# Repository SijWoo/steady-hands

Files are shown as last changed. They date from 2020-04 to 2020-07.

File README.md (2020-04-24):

# Introduction
This repo contains the src files and hardware for a wearable wrist band that treats chronic shaky hands.

## Background
Tremors make your hands or other parts of your body involuntarily move and shake. Severe cases can even make everday tasks difficult. This device is to let people from mild to severe cases regain control through the use of vibration feedback.

## How it works
Overloading the sensory nerves can surpress the involuntary movement. Vibration motors are implemented inside the wearable to constantly stimulate the nerves.

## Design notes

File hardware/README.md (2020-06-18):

# Hardware
Descriptions and explanations

## Components
| Description | P/N |
| --- | --- |
| Microcontroller | STM32F411CE |
| Vibrating Motors | |
| IMU | BNO055 |

## Microcontroller
The STM32f411CE controls the vibration motors.

## Vibrating Motors
Small motors for phones are repurposed for this project. A transistor interface is needed to drive the required current.

## IMU
The BNO055 uses the I2C interface.

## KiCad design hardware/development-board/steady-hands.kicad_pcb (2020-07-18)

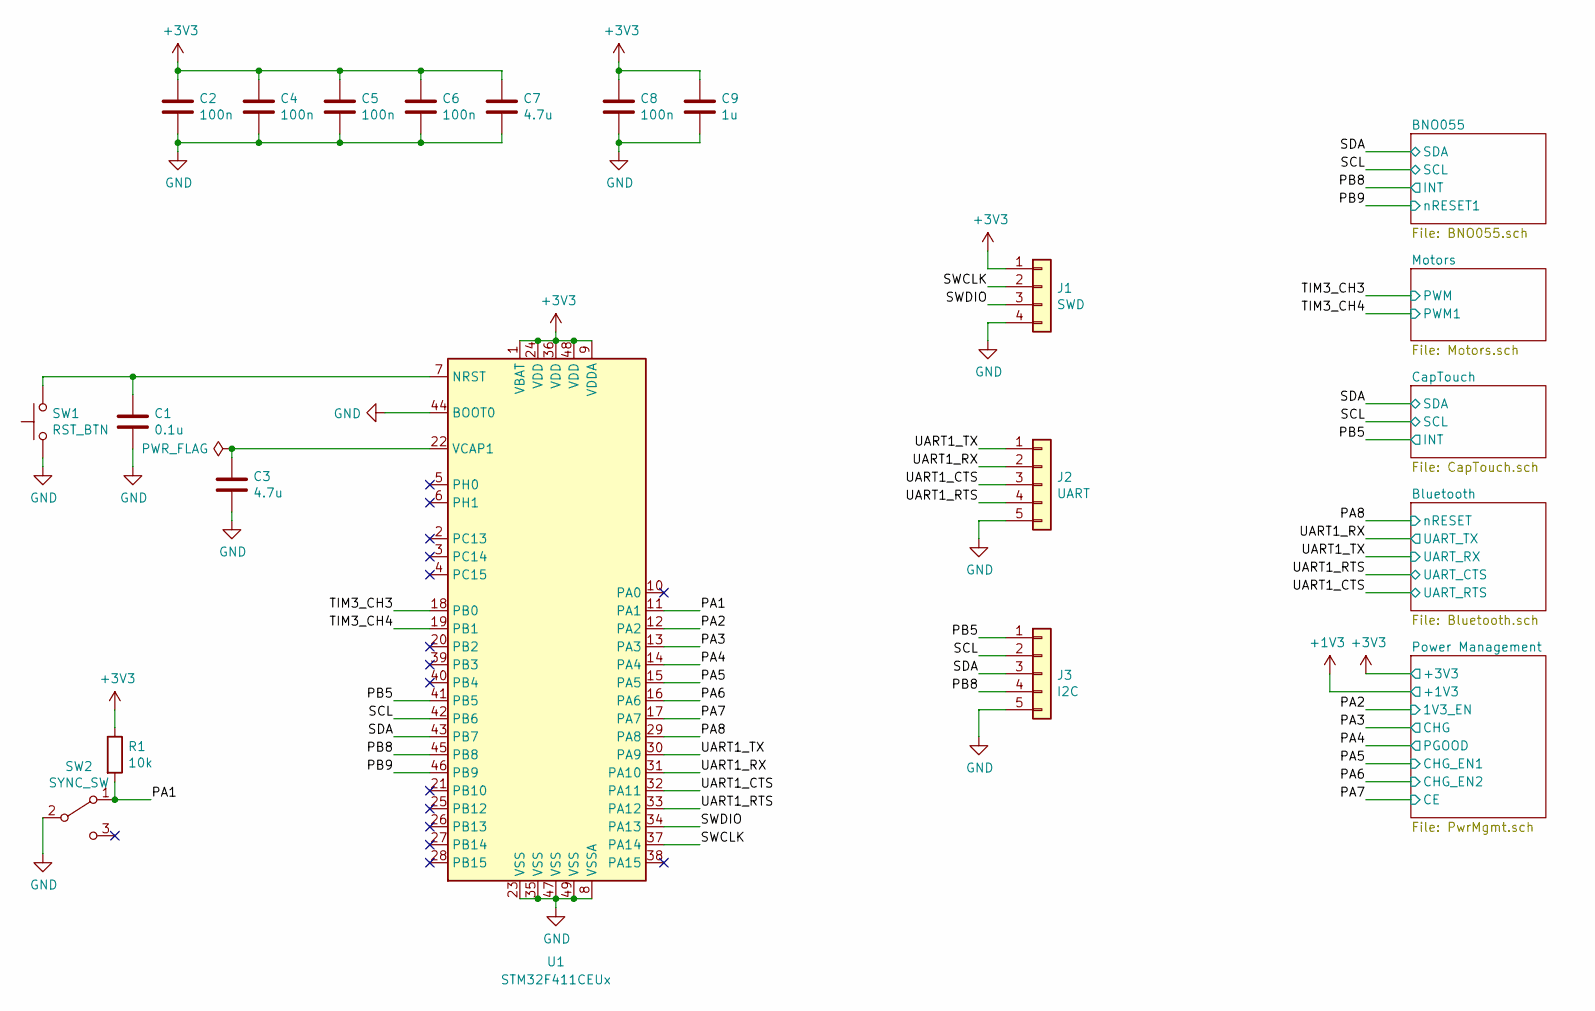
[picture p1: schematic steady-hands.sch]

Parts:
C1: 0.1u; C_0402_1005Metric
C2, C4, C5, C6, C8: 100n; C_0402_1005Metric
C3, C7: 4.7u; C_0402_1005Metric
C9: 1u; C_0402_1005Metric
J1: SWD; PinHeader_1x04_P1.27mm_Vertical
J2: UART; PinHeader_1x05_P1.27mm_Vertical
J3: I2C; PinHeader_1x05_P1.27mm_Vertical
R1: 10k; R_0402_1005Metric
SW1: RST_BTN; SW_SPST_B3U-1000P
SW2: SYNC_SW; EG1224
U1: STM32F411CEUx; QFN-48-1EP_7x7mm_P0.5mm_EP5.6x5.6mm

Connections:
+3V3: C2.1, C4.1, C5.1, C6.1, C7.1, C8.1, C9.1, J1.1, R1.1, U1.1 (VBAT), U1.9 (VDDA), U1.24 (VDD), U1.36 (VDD), U1.48 (VDD); also elsewhere on the board
/PA1: R1.2, SW2.1 (A), U1.11 (PA1)
/PA2: U1.12 (PA2); also elsewhere on the board
/PA3: U1.13 (PA3); also elsewhere on the board
/PA4: U1.14 (PA4); also elsewhere on the board
/PA5: U1.15 (PA5); also elsewhere on the board
/PA6: U1.16 (PA6); also elsewhere on the board
/PA7: U1.17 (PA7); also elsewhere on the board
/PA8: U1.29 (PA8); also elsewhere on the board
/PB5: J3.1, U1.41 (PB5); also elsewhere on the board
/PB8: J3.4, U1.45 (PB8); also elsewhere on the board
/PB9: U1.46 (PB9); also elsewhere on the board
/SCL: J3.2, U1.42 (PB6); also elsewhere on the board
/SDA: J3.3, U1.43 (PB7); also elsewhere on the board
/SWCLK: J1.2, U1.37 (PA14)
/SWDIO: J1.3, U1.34 (PA13)
/TIM3_CH3: U1.18 (PB0); also elsewhere on the board
/TIM3_CH4: U1.19 (PB1); also elsewhere on the board
/UART1_CTS: J2.3, U1.32 (PA11); also elsewhere on the board
/UART1_RTS: J2.4, U1.33 (PA12); also elsewhere on the board
/UART1_RX: J2.2, U1.31 (PA10); also elsewhere on the board
/UART1_TX: J2.1, U1.30 (PA9); also elsewhere on the board
GND: C1.2, C2.2, C3.2, C4.2, C5.2, C6.2, C7.2, C8.2, C9.2, J1.4, J2.5, J3.5, SW1.1, SW2.2 (B), U1.8 (VSSA), U1.23 (VSS), U1.35 (VSS), U1.44 (BOOT0), U1.47 (VSS), U1.49 (VSS); also elsewhere on the board
unnamed: C1.1, SW1.2, U1.7 (NRST)
unnamed: C3.1, U1.22 (VCAP1)

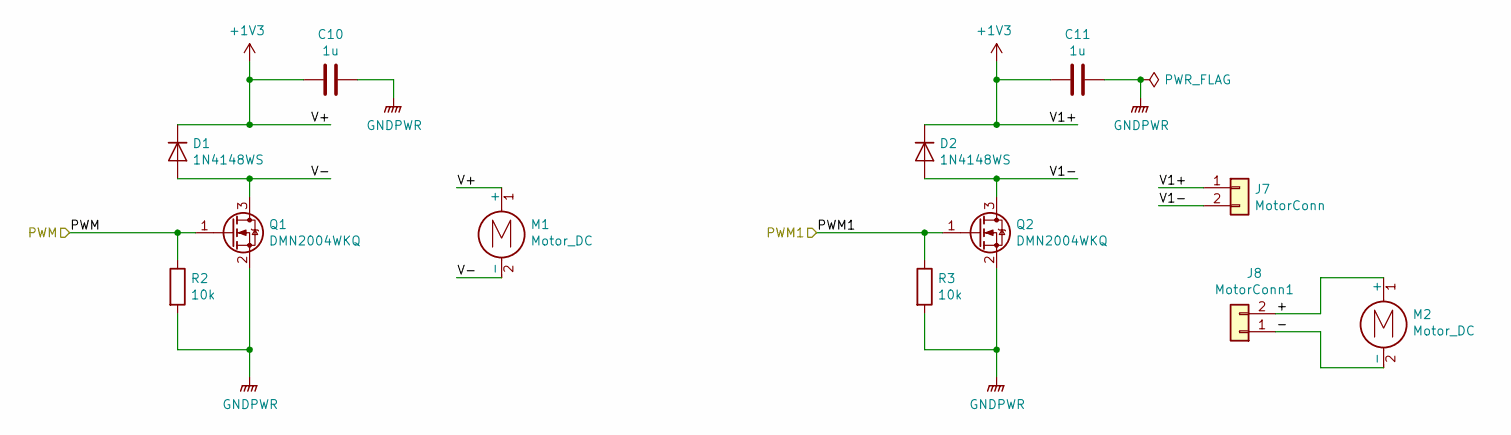
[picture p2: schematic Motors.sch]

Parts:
C10, C11: 1u; C_0402_1005Metric
D1, D2: 1N4148WS; D_SOD-323
J7: MotorConn; PinHeader_1x02_P1.27mm_Vertical
J8: MotorConn1; PinHeader_1x02_P1.27mm_Vertical
M1, M2: Motor_DC; 316040005
Q1, Q2: DMN2004WKQ; SOT-323_SC-70
R2, R3: 10k; R_0402_1005Metric

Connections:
+1V3: C10.2, C11.2, D1.1 (K), D2.1 (K), J7.1, M1.1 (+); also elsewhere on the board
/Motors/V1-: D2.2 (A), J7.2, Q2.3 (D)
/Motors/V-: D1.2 (A), M1.2 (-), Q1.3 (D)
/TIM3_CH3: Q1.1 (G), R2.1; also elsewhere on the board
/TIM3_CH4: Q2.1 (G), R3.1; also elsewhere on the board
GNDPWR: C10.1, C11.1, Q1.2 (S), Q2.2 (S), R2.2, R3.2
unnamed: J8.1, M2.2 (-)
unnamed: J8.2, M2.1 (+)

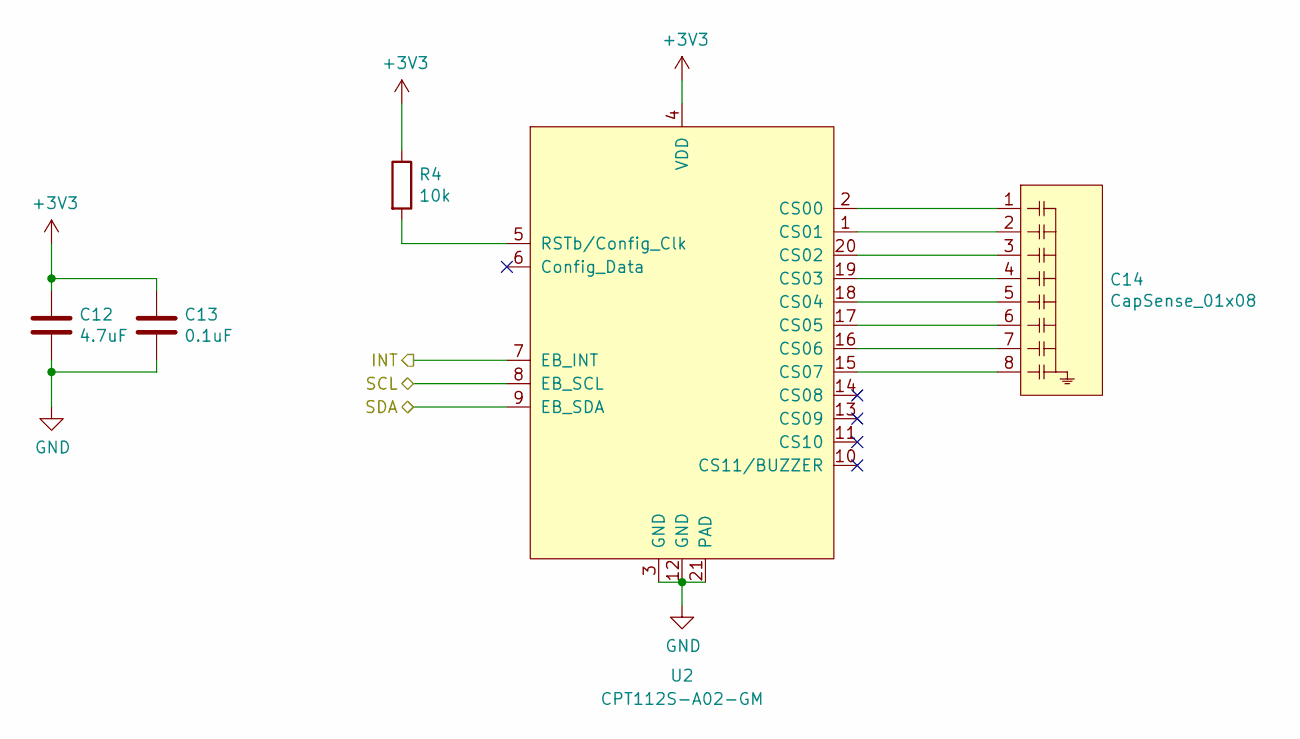
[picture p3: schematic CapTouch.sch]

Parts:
C12: 4.7uF; C_0402_1005Metric
C13: 0.1uF; C_0402_1005Metric
C14: CapSense_01x08; TouchSlider-8_35x10mm
R4: 10k; R_0402_1005Metric
U2: CPT112S-A02-GM

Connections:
+3V3: C12.1, C13.1, R4.1, U2.4 (VDD); also elsewhere on the board
/PB5: U2.7 (EB_INT); also elsewhere on the board
/SCL: U2.8 (EB_SCL); also elsewhere on the board
/SDA: U2.9 (EB_SDA); also elsewhere on the board
GND: C12.2, C13.2, U2.3 (GND), U2.12 (GND), U2.21 (PAD); also elsewhere on the board
unnamed: C14.1, U2.2 (CS00)
unnamed: C14.2, U2.1 (CS01)
unnamed: C14.3, U2.20 (CS02)
unnamed: C14.4, U2.19 (CS03)
unnamed: C14.5, U2.18 (CS04)
unnamed: C14.6, U2.17 (CS05)
unnamed: C14.7, U2.16 (CS06)
unnamed: C14.8, U2.15 (CS07)
unnamed 60: R4.2, U2.5 (RSTb/Config_Clk); also elsewhere on the board

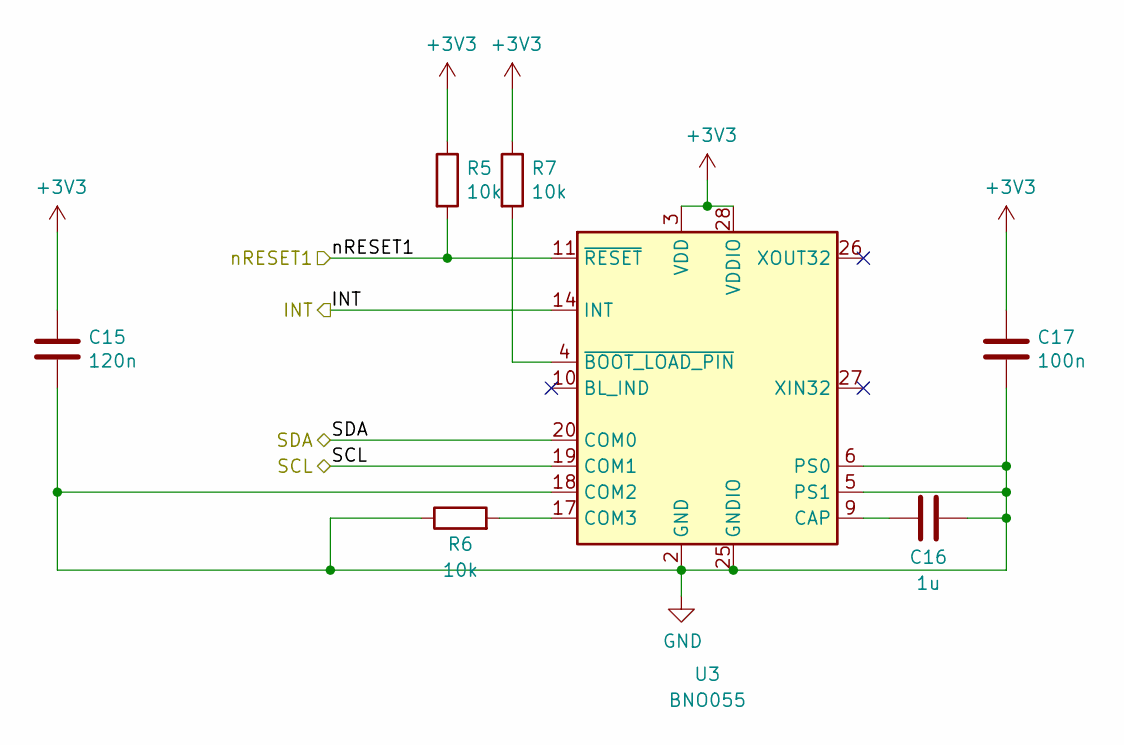
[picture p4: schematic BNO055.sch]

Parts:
C15: 120n; C_0402_1005Metric
C16: 1u; C_0402_1005Metric
C17: 100n; C_0402_1005Metric
R5, R6, R7: 10k; R_0402_1005Metric
U3: BNO055; LGA-28_5.2x3.8mm_P0.5mm

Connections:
+3V3: C15.1, C17.1, R5.1, R7.1, U3.3 (VDD), U3.28 (VDDIO); also elsewhere on the board
/PB8: U3.14 (INT); also elsewhere on the board
/PB9: R5.2, U3.11 (~RESET); also elsewhere on the board
/SCL: U3.19 (COM1); also elsewhere on the board
/SDA: U3.20 (COM0); also elsewhere on the board
GND: C15.2, C16.1, C17.2, R6.1, U3.2 (GND), U3.5 (PS1), U3.6 (PS0), U3.15 (GNDIO), U3.16 (GNDIO), U3.18 (COM2), U3.25 (GNDIO); also elsewhere on the board
unnamed: C16.2, U3.9 (CAP)
unnamed: R6.2, U3.17 (COM3)
unnamed: R7.2, U3.4 (~BOOT_LOAD_PIN)

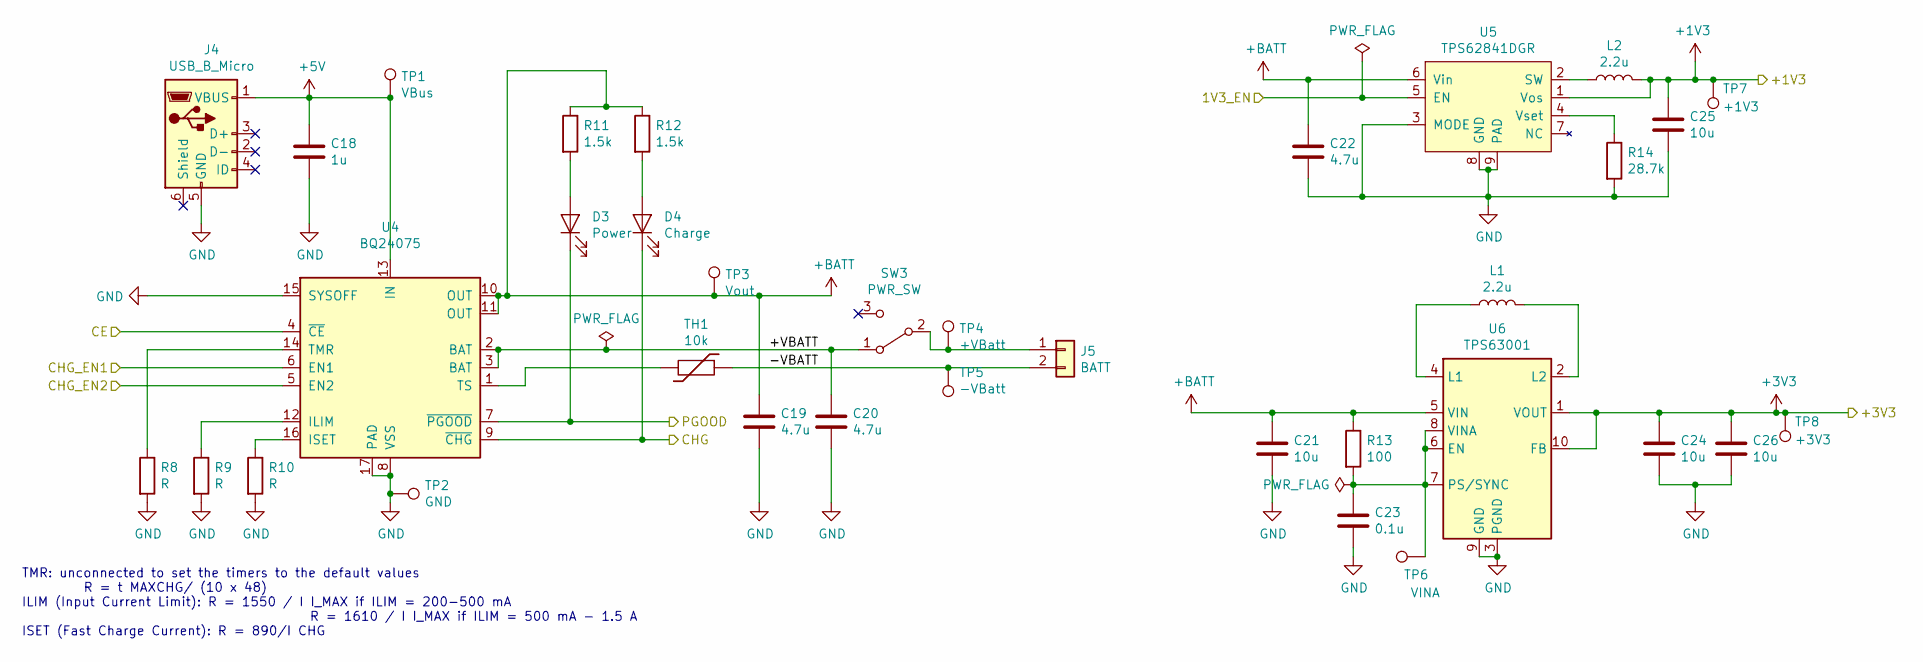
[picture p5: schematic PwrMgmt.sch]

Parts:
C18: 1u; C_0402_1005Metric
C19, C20, C22: 4.7u; C_0402_1005Metric
C21, C24, C25, C26: 10u; C_0402_1005Metric
C23: 0.1u; C_0402_1005Metric
D3: Power; LED_0402_1005Metric
D4: Charge; LED_0402_1005Metric
J4: USB_B_Micro; USB_Micro-B_Molex-105017-0001
J5: BATT; JST_PH_B2B-PH-SM4-TB_1x02-1MP_P2.00mm_Vertical
L1, L2: 2.2u; L_0402_1005Metric
R8, R9, R10: R; R_0402_1005Metric
R11, R12: 1.5k; R_0402_1005Metric
R13: 100; R_0402_1005Metric
R14: 28.7k; R_0402_1005Metric
SW3: PWR_SW; EG1224
TH1: 10k; R_0402_1005Metric
TP1: VBus; TestPoint_Pad_D1.0mm
TP2: GND; TestPoint_Pad_1.0x1.0mm
TP3: Vout; TestPoint_Pad_D1.0mm
TP4: +VBatt; TestPoint_Pad_D1.0mm
TP5: -VBatt; TestPoint_Pad_D1.0mm
TP6: VINA; TestPoint_Pad_D1.0mm
TP7: +1V3; TestPoint_Pad_D1.0mm
TP8: +3V3; TestPoint_Pad_D1.0mm
U4: BQ24075; QFN-16-1EP_3x3mm_P0.5mm_EP1.7x1.7mm
U5: TPS62841DGR; HVSSOP-8-1EP_3x3mm_P0.065mm_EP2.2x3.1mm_Mask1.35x1.65mm
U6: TPS63001; Texas_DRC0010J_ThermalVias

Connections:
+1V3: C25.1, L2.2, TP7.1, U5.1 (Vos); also elsewhere on the board
+3V3: C24.1, C26.1, TP8.1, U6.1 (VOUT), U6.10 (FB); also elsewhere on the board
+5V: C18.1, J4.1 (VBUS), TP1.1, U4.13 (IN)
+BATT: C19.1, C21.1, C22.1, R11.1, R12.1, R13.1, TP3.1, U4.10 (OUT), U4.11 (OUT), U5.6 (Vin), U6.5 (VIN)
/PA2: U5.5 (EN); also elsewhere on the board
/PA3: D4.1 (K), U4.9 (~CHG); also elsewhere on the board
/PA4: D3.1 (K), U4.7 (~PGOOD); also elsewhere on the board
/PA5: U4.6 (EN1); also elsewhere on the board
/PA6: U4.5 (EN2); also elsewhere on the board
/PA7: U4.4 (~CE); also elsewhere on the board
/Power Management/+VBATT: C20.1, SW3.1 (A), U4.2 (BAT), U4.3 (BAT)
/Power Management/-VBATT: J5.2, TH1.1, TP5.1
GND: C18.2, C19.2, C20.2, C21.2, C22.2, C23.2, C24.2, C25.2, C26.2, J4.5 (GND), R8.2, R9.2, R10.2, R14.2, TP2.1, U4.8 (VSS), U4.15 (SYSOFF), U4.17 (PAD), U5.3 (MODE), U5.8 (GND), U5.9 (PAD), U6.3 (PGND), U6.9 (GND), U6.11 (PGND); also elsewhere on the board
unnamed: C23.1, R13.2, TP6.1, U6.6 (EN), U6.7 (PS/SYNC), U6.8 (VINA)
unnamed: D3.2 (A), R11.2
unnamed: D4.2 (A), R12.2
unnamed: J5.1, SW3.2 (B), TP4.1
unnamed: L1.1, U6.4 (L1)
unnamed: L1.2, U6.2 (L2)
unnamed: L2.1, U5.2 (SW)
unnamed: R8.1, U4.14 (TMR)
unnamed: R9.1, U4.12 (ILIM)
unnamed: R10.1, U4.16 (ISET)
unnamed: R14.1, U5.4 (Vset)
unnamed: TH1.2, U4.1 (TS)

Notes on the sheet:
TMR: unconnected to set the timers to the default values R = t MAXCHG/ (10 x 48) ILIM (Input Current Limit): R = 1550 / I I_MAX if ILIM = 200-500 mA R = 1610 / I I_MAX if ILIM = 500 mA - 1.5 A ISET (Fast Charge Current): R = 890/I CHG

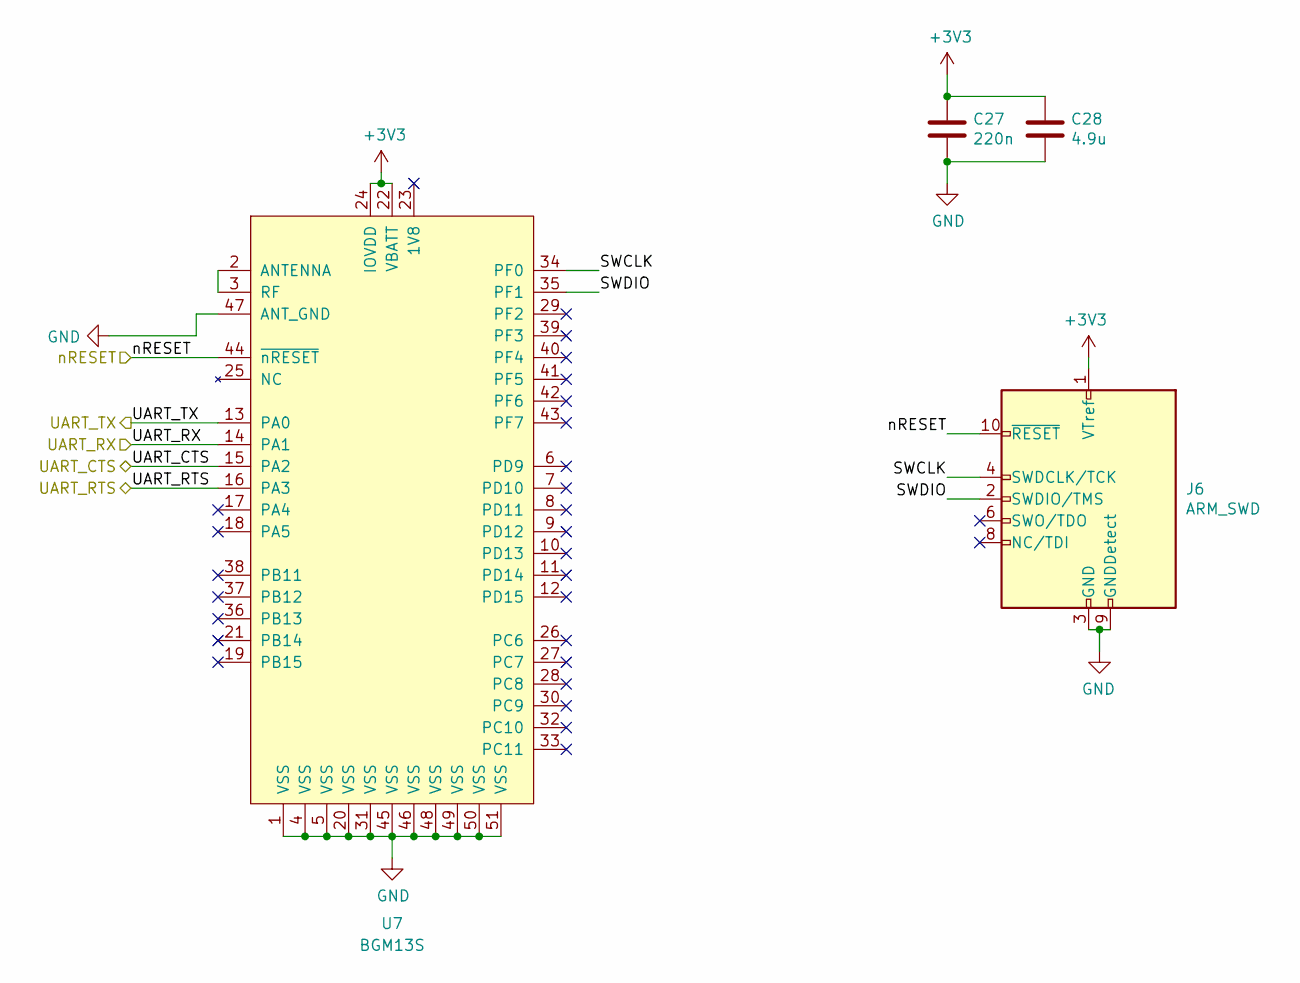
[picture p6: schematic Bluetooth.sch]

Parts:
C27: 220n; C_0402_1005Metric
C28: 4.9u; C_0402_1005Metric
J6: ARM_SWD; FTSH-105-01-L-DV-K
U7: BGM13S

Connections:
+3V3: C27.1, C28.1, J6.1 (VTref), U7.22 (VBATT), U7.24 (IOVDD); also elsewhere on the board
/Bluetooth/SWCLK: J6.4 (SWDCLK/TCK), U7.34 (PF0)
/Bluetooth/SWDIO: J6.2 (SWDIO/TMS), U7.35 (PF1)
/PA8: J6.10 (~RESET~), U7.44 (~nRESET); also elsewhere on the board
/UART1_CTS: U7.16 (PA3); also elsewhere on the board
/UART1_RTS: U7.15 (PA2); also elsewhere on the board
/UART1_RX: U7.13 (PA0); also elsewhere on the board
/UART1_TX: U7.14 (PA1); also elsewhere on the board
GND: C27.2, C28.2, J6.3 (GND), J6.5 (GND), J6.9 (GNDDetect), U7.1 (VSS), U7.4 (VSS), U7.5 (VSS), U7.20 (VSS), U7.31 (VSS), U7.45 (VSS), U7.46 (VSS), U7.47 (ANT_GND), U7.48 (VSS), U7.49 (VSS), U7.50 (VSS), U7.51 (VSS); also elsewhere on the board
unnamed: U7.2 (ANTENNA), U7.3 (RF)

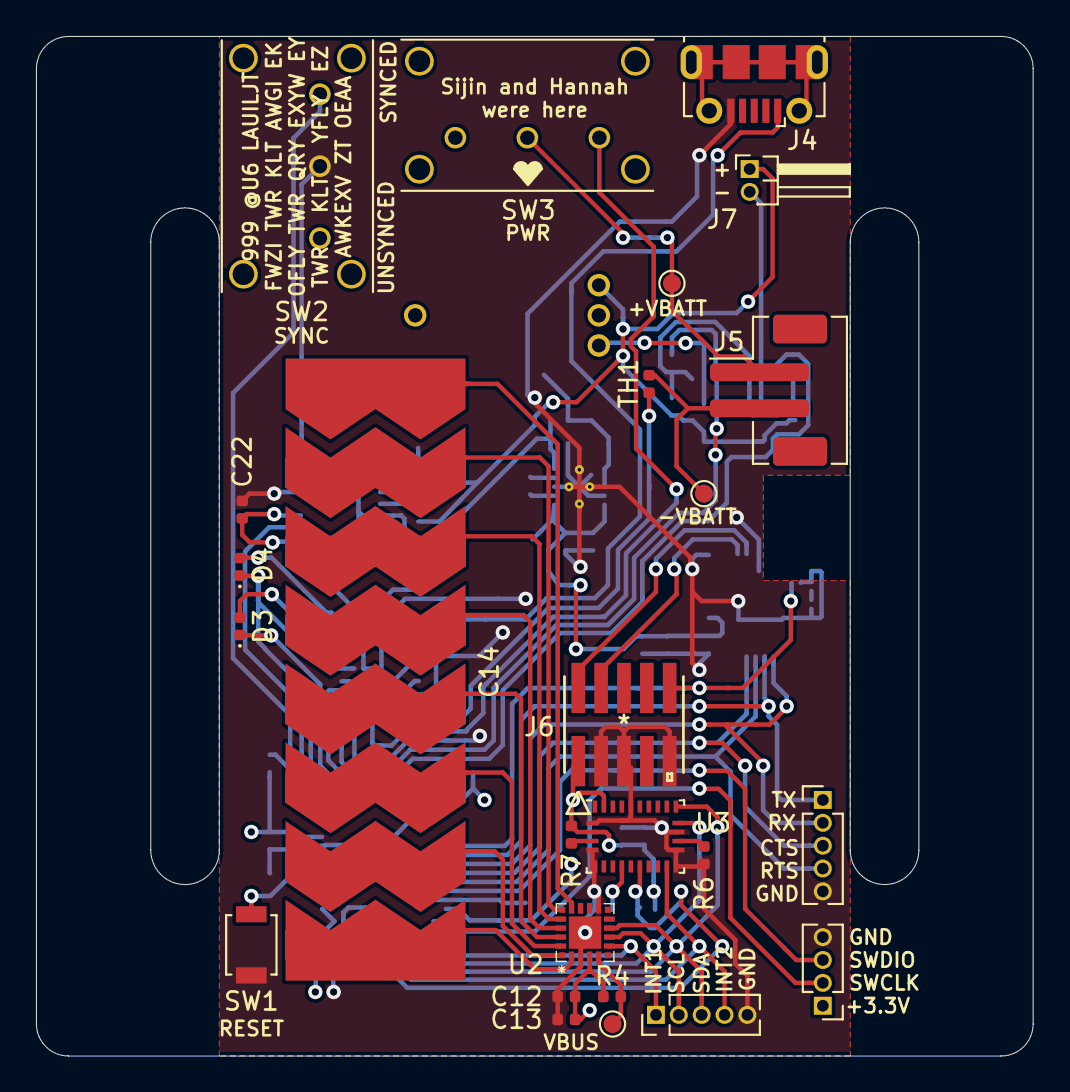
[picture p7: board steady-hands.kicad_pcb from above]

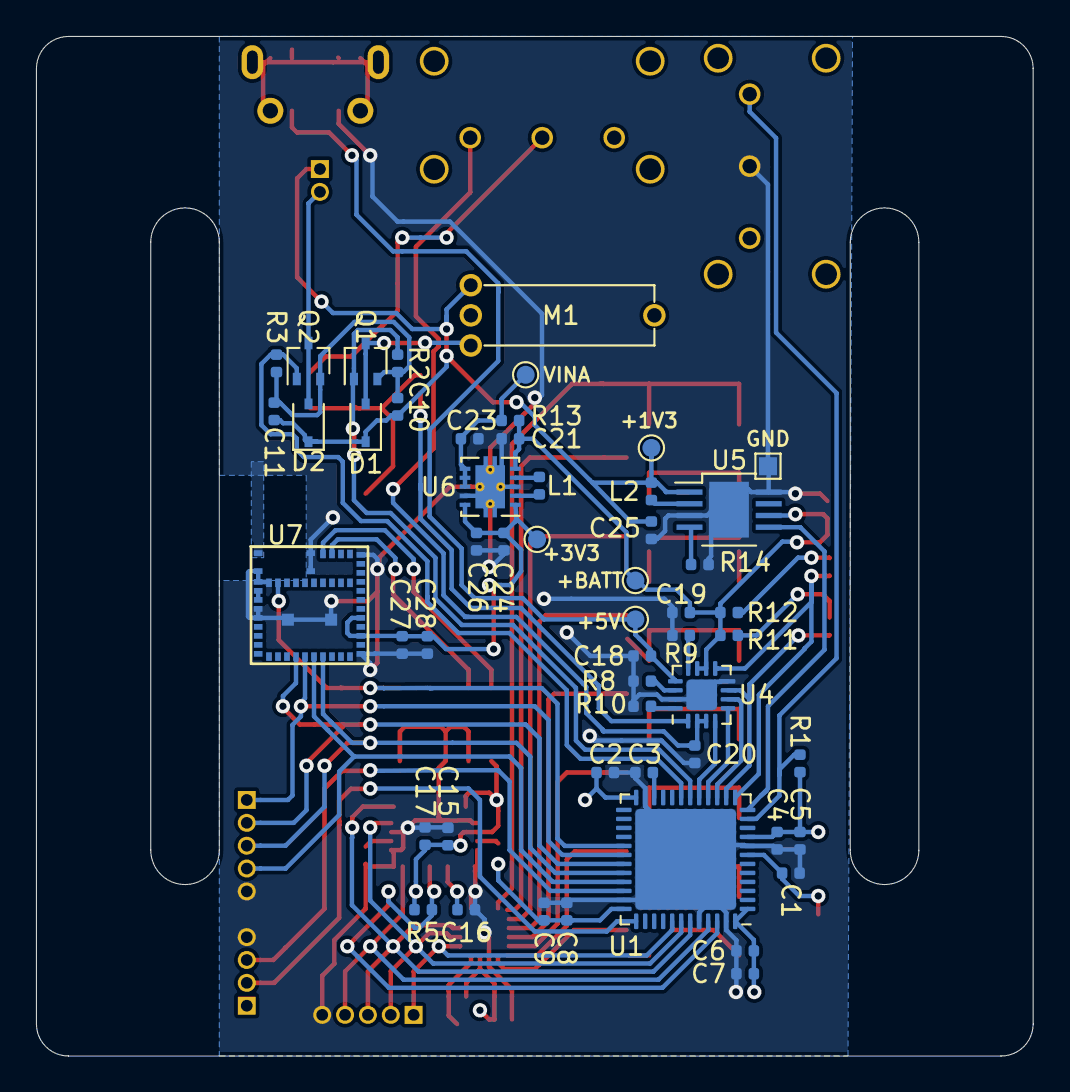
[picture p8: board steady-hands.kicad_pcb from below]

Board: 4 copper layers, 55.4 x 56.6 mm, 78 parts (53 on the bottom side), 60 nets.

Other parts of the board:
TP1#2: TestPoint; TestPoint_Pad_D1.0mm

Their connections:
unnamed 60: TP1#2.1; also elsewhere on the board

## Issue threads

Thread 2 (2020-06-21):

Create development board to test code

SijWoo, 2020-06-21:
The final product will be a flexible PCB but due to the price and manufacturing, making a development board for testing will be more cost effective. The following parts are used:
1. STM32F411
2. IMU
3. Capacitive Touch
4. Power Management
5. Bluetooth Module
6. Vibrating motors

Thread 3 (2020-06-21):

Write vibrating motor driver

SijWoo, 2020-06-21:
There are bsp and drv src files for the vibrating motor. The bsp file is for chip specific/dependent code. The bsp_motor.c src file should have IO initialization and PWM control code. The drv_motor.c file should have code that calculates duty cycle, calibration on the min/max limits of the PWM, etc. The application code will call the drv_motor code. the drv_motor code will call the bsp_motor code.

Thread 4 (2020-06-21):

Write BNO055 driver

SijWoo, 2020-06-21:
Write the driver to get IMU data from the BNO055 component. The bsp_bno055.c src file should have basic I2C/GPIO pin controls such as read/write functions. The drv_bno055.c src file should have code that uses the bsp_bno055.c functions and parses/calculates the data. The application code will call the drv_bno055.c code, the drv_bno055.c will call the bsp_bno055.c code.

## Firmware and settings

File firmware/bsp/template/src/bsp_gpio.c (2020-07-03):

#include "common.h"
#include "stm32f4xx_ll_bus.h"
#include "stm32f4xx_ll_gpio.h"

/**
 * Documentation for the STM32F411:
 */

/**
 * @brief   Initializes the GPIO ports/pins that are connected to the modules.
 * @note    The necessary input pins that requires an interrupt are initialized.
 * @note    The module pins can be differentiated with the <x>id_t types.
 *          Look in common.h for more info.
 * @param   None
 * @return  None
 */
void BSP_GPIO_Init(void) {
    
}

/**
 * @brief   Attaches a handler to an interrupt pin.
 * @param   iid     The module's INT ID
 * @param   handler Function that will run whenever there INT pin it triggered.
 */
void BSP_GPIO_AttachISR(intid_t iid, void (*handler)(void)) {

}

/**
 * @brief   Sets the state of the Reset Pin of the specific module.
 * @param   rid     The module's reset ID.
 * @param   state   LOW or HIGH
 * @return  None
 */
void BSP_GPIO_SetRstState(rstid_t rid, pin_state_t state) {

}

/**
 * @brief   Gets the state of the INT pin of the specific module.
 * @param   iid     The module's INT ID.
 * @return  pin_state_t (LOW or HIGH)
 */
pin_state_t BSP_GPIO_GetIntState(intid_t iid) {
    
}

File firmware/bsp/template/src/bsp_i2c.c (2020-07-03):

#include "common.h"

/**
 * @brief   Initializes the I2C port.
 * @param   None
 * @return  None
 */
void BSP_I2C_Init(void) {
    
}

/**
 * @brief   Sends data buffer onto the I2C bus.
 * @param   devID   7-bit device ID.
 * @param   regAddr 16-bit register address inside the bus that the data will
 *                  write to.
 * @param   data    Data buffer that holds the data that will be written.
 * @param   len     Length of the data buffer.
 * @return  Number of bytes that was written to the bus.
 */
int32_t BSP_I2C_Write(uint8_t devId, uint16_t regAddr, uint8_t *data, uint32_t len) {
    
}

/**
 * @brief   Gets data from the I2C bus.
 * @pre     Data buffer parameter must be statically allocated.
 * @param   devID   7-bit device ID.
 * @param   regAddr 16-bit register address inside the bus to read the data
 *                  from the bus.
 * @param   data    Data buffer that will hold the data that will be read from
 *                  the bus. This buffer must be statically allocated before
 *                  calling this function.
 * @param   len     Length of the data buffer. 
 * @return  Number of bytes that was written to the bus.
 */
int32_t BSP_I2C_Read(uint8_t devId, uint16_t regAddr, uint8_t *data, uint32_t len) {
    
}

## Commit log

2020-04-25 Adds apps and drivers
2020-06-18 Adds development board schematic
    [steady-hands.kicad_pcb, steady-hands.sch]
2020-06-21 Starter project compiles for stm32f411
2020-06-25 Creates prototypes for BSP_BNO055
2020-06-25 Creates prototypes for BSP_Motor
2020-06-25 Creates prototypes for Drv_Motor
2020-06-28 Edits development board schematic
    [APDS-9960.sch, BNO055.sch, Bluetooth.sch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]
2020-07-03 Edits motor functions to control multiple motors
2020-07-03 Adds new components
    [APDS-9960.sch, BNO055.sch, Bluetooth.sch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]
2020-07-03 Adds symbol library
    [CapTouch.sch, PMIC.sch, steady-hands.sch]
2020-07-03 Removes gitignore for kicad libraries
2020-07-03 Feature/bsp structure (#6)
    * Adds new BSP src files for new structure since some bsp modules are used multiple times in the drivers
    * Adds new BSP src files for new structure since some bsp modules are used multiple times in the drivers
    * Adds new BSP src files for new structure since some bsp modules are used multiple times in the drivers
    * Adds documentation to bsp src files
    * Adds missing bracket
    [APDS-9960.sch, BNO055.sch, Bluetooth.sch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]
2020-07-03 Edits power management
    [PMIC.sch]
2020-07-08 Adds power management components
    [CapTouch.sch, PMIC.sch, PwrMgmtsch.sch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]
2020-07-09 Edits power management components
    [CapTouch.sch, PwrMgmtsch.sch, steady-hands.sch]
2020-07-09 Adds second motor components
    [Motors.sch, steady-hands.sch]
2020-07-09 Completes schematic connections
    [APDS-9960.sch, BNO055.sch, Bluetooth.sch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]
2020-07-09 Edits gitignore to ignore temporary kicad files
2020-07-09 Deletes unnecessary kicad files
2020-07-10 Edits label names and switch configuration
    [BNO055.sch, Bluetooth.sch, CapTouch.sch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]
2020-07-13 Updates files. Just making sure everything I didn't create any errors
    [CapTouch.sch]
2020-07-13 Deletes unnecessary files
    [Motors.sch, PwrMgmt.sch]
2020-07-14 Adds footprints
    [APDS-9960.sch, BNO055.sch, Bluetooth.sch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]
2020-07-14 Adds IC footprints
    [PwrMgmt.sch]
2020-07-14 Adds all footprints to board
    [Bluetooth.sch, Motors.sch, PwrMgmt.sch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]
2020-07-17 Edits PCB layout
    [BNO055.sch, Bluetooth.sch, CapTouch.sch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]
2020-07-18 Designs PCB layout of development board
    [APDS-9960.sch, BNO055.sch, Bluetooth.sch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]

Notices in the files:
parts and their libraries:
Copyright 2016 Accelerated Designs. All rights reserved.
